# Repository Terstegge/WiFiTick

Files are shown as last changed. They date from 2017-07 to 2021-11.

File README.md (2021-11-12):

# WiFiTick
Small ESP8266-based WLAN board for the MSP432 launchpad.

Here you see WiFiTick attached to the MSP432 launchpad with an
additional EDU MKII booster pack above:

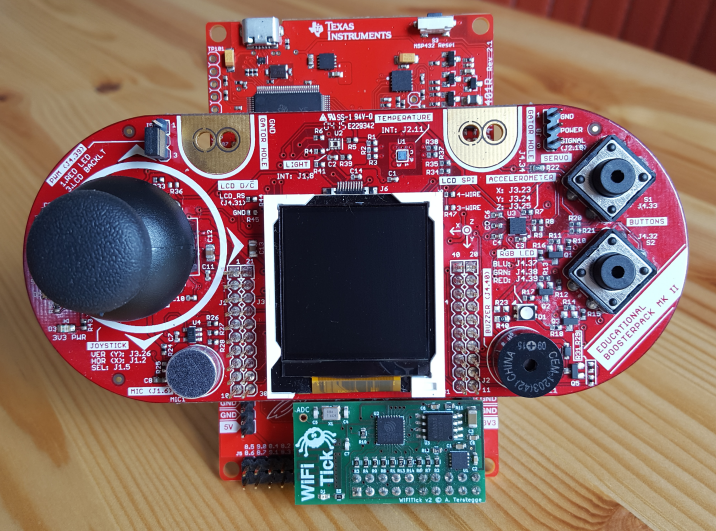
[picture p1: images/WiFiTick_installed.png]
WiFiTick picture 1


WiFiTick front and back view:

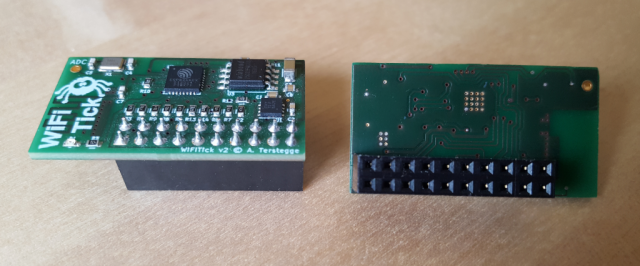
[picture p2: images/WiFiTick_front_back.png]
WiFiTick picture 2


WiFiTick is a small add-on board for the
[MSP432 lauchpad](http://www.ti.com/tool/MSP-EXP432P401R) from Texas Instruments.
The MSP432 launchpad is a nice microcontroller board with a Cortex M4F processor
and a on-board debug facility. WiFiTick adds WiFi functionality to the lauchpad,
using a ESP8266, which is a cheap but very powerful WLAN-enabled microcontroller
from Espressif.

Texas Instruments have their own WiFi solution (e.g. the CC3100 booster pack).
But these boards have to be disconnected from the lauchpad when you want to 
flash a new firmware to the WiFi board. This makes it a little bit unhandy for
students.

WiFiTick has the following features:

* Low cost - ideal for WiFi enabled student projects
  (WiFi client and WiFi access point modes available)
* 4 MiB flash, so lots of space for ESP8266 programs and
  embedded file systems (SPIFFS) 
* Integrated PCB antenna
* Single 5V power supply (via USB/launchpad). There is a separate
  3.3V regulator on the board.
* No interference with other booster packs, because the additional 
  horizontal header of the MSP432 lauchpad is used
* No need to disconnect from launchpad: With a special software, the MSP432
  launchpad serves as a programming adapter (via a UART interface). This
  software features automatic baud rate control, so boot messages of the
  ESP8266 are readable.
* Easy programming of ESP8266 with Arduino IDE
* Full control of the ESP8266 from MSP432 side. The MSP432 can ...
    * Reset, Power up/down or wake up the ESP8266
    * Communicate with the ESP8266 via SPI (or any other protocol -
      there are 8 GPIOs plus the programming UART available for
      data exchange).
* Additional ADC input pad for the ESP8266
* User-controllable LED on the board (can e.g. simulate the behaviour of the
  LED on the well-known ESP-12E/F boards)

This project contains the hardware design files, which were developed
using [KiCad EDA](http://kicad.org/). The related software will be
published in a separate project.

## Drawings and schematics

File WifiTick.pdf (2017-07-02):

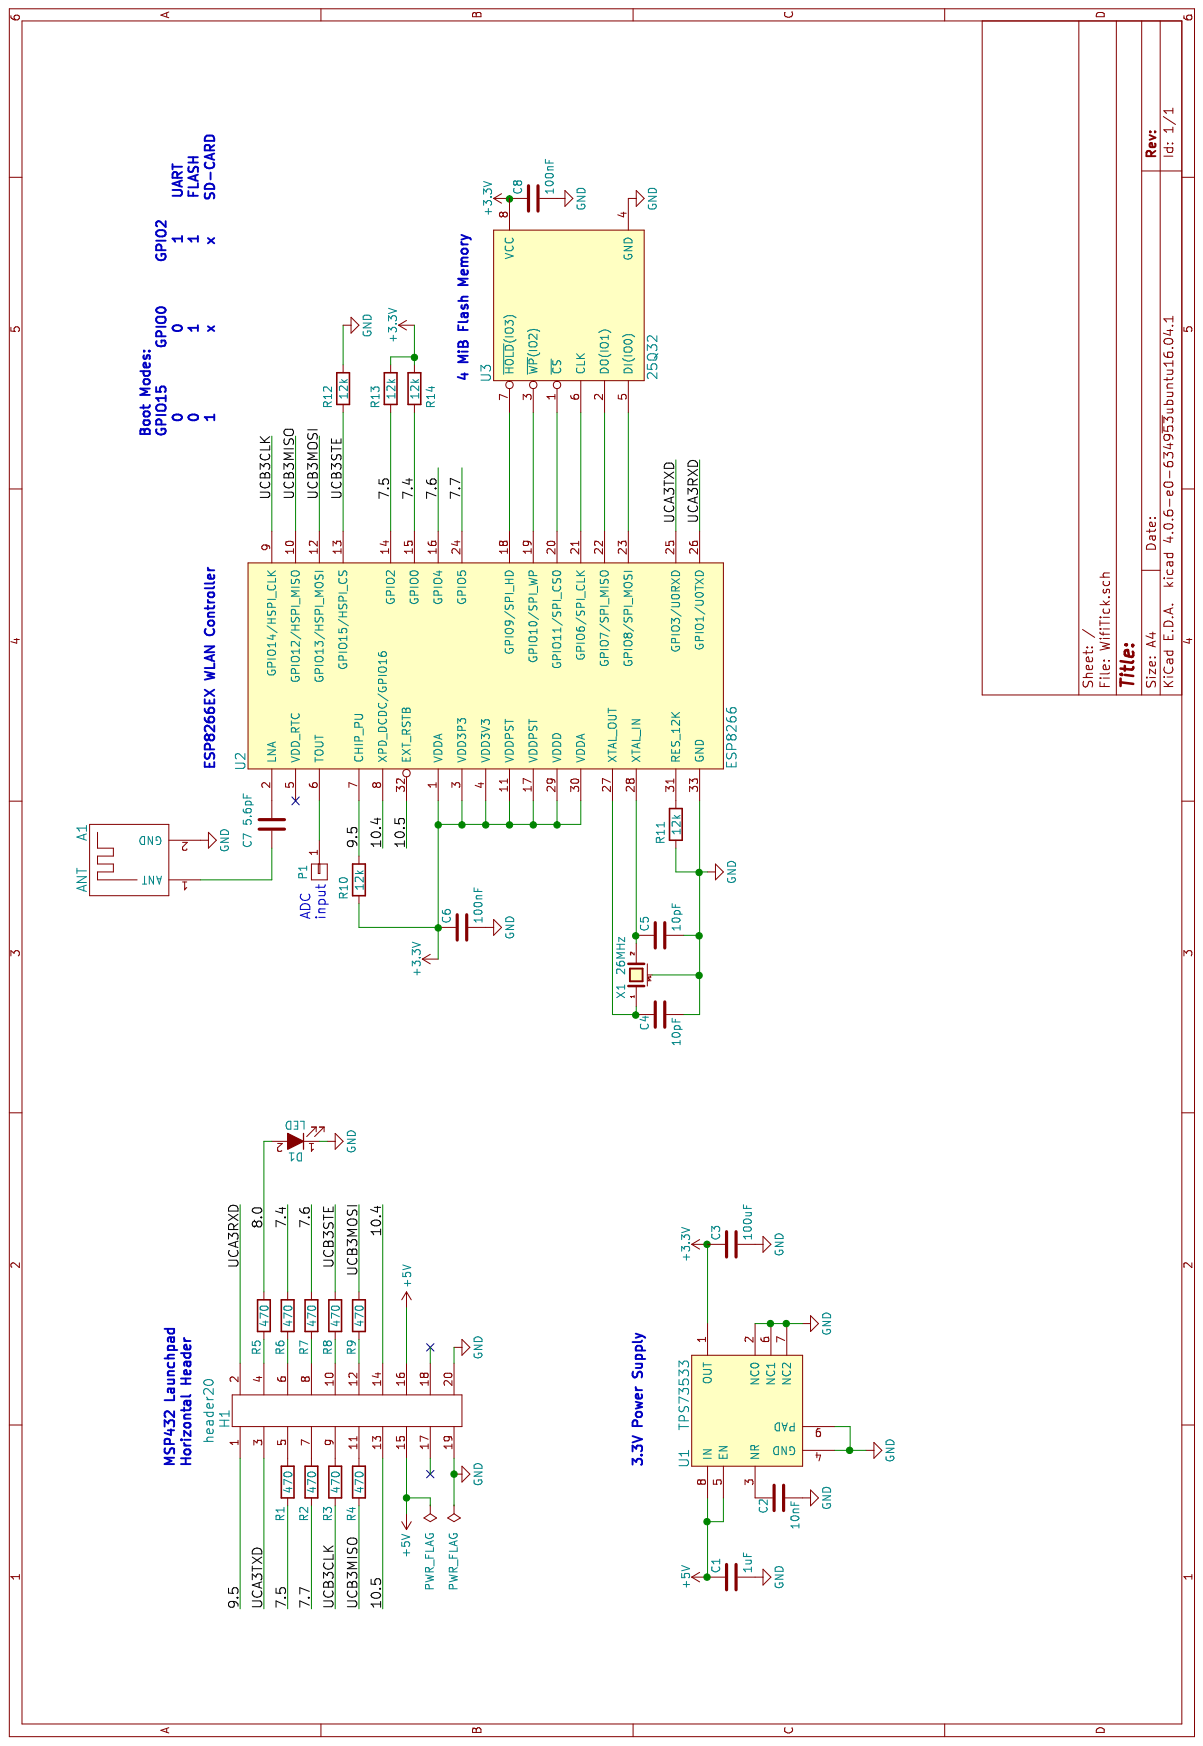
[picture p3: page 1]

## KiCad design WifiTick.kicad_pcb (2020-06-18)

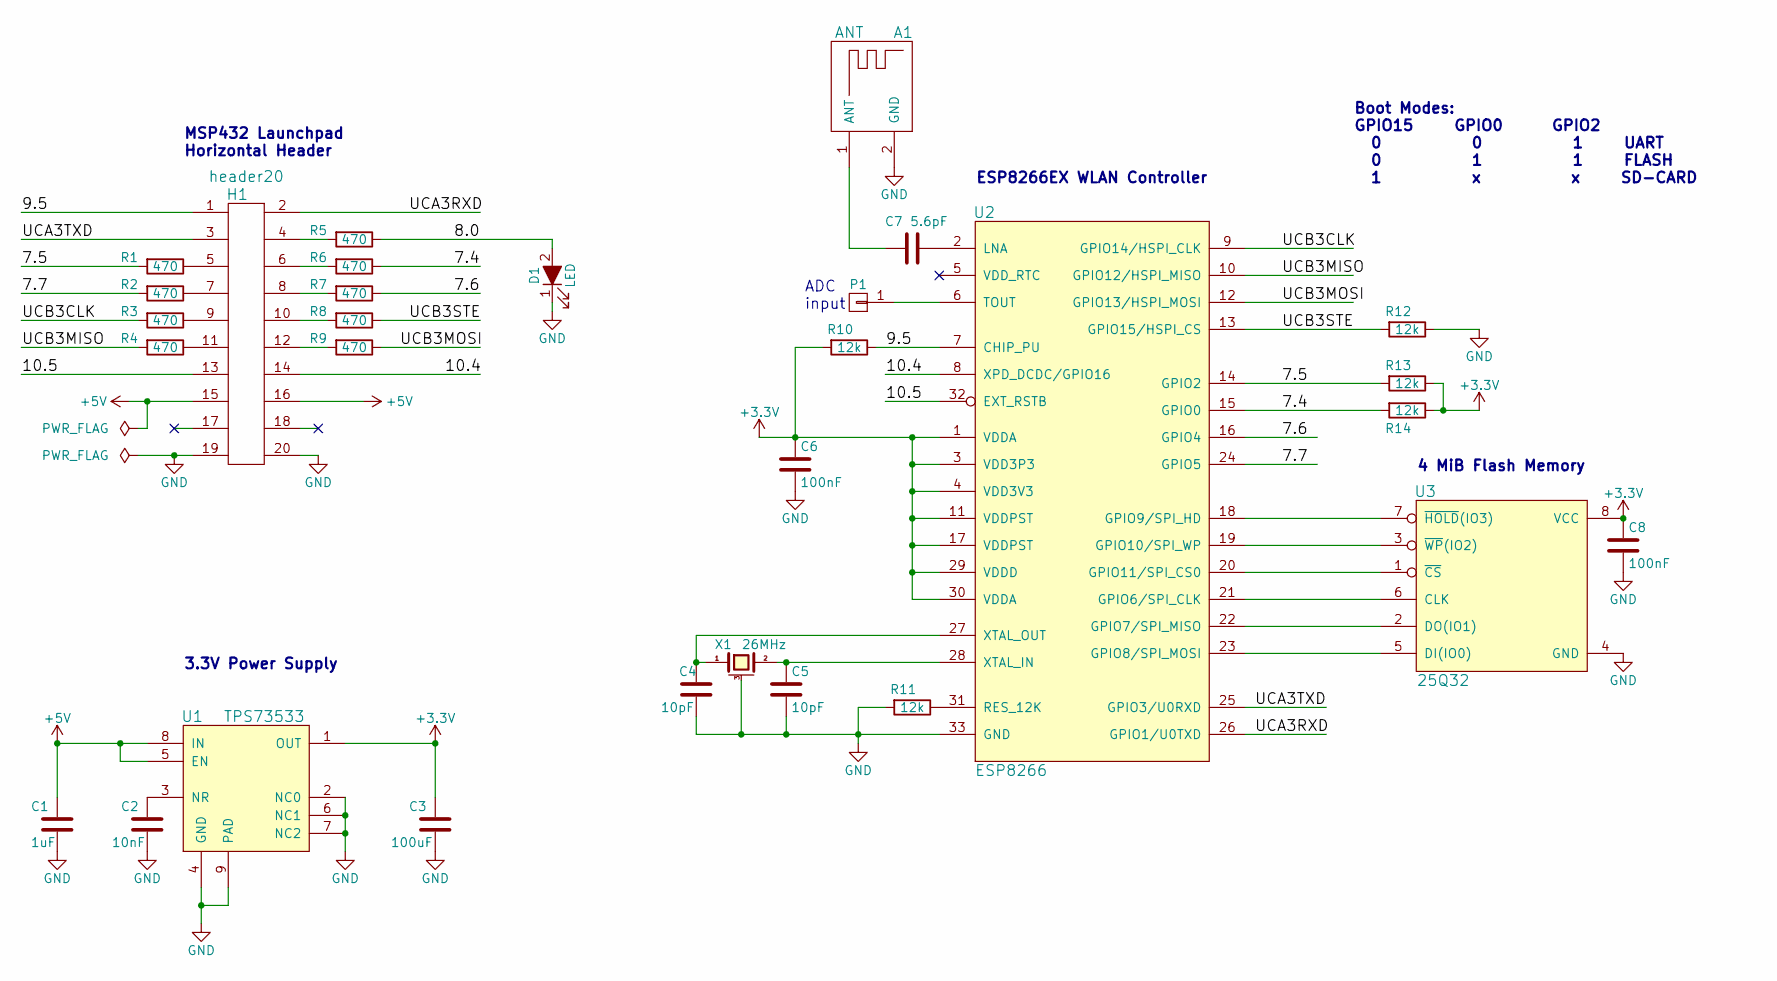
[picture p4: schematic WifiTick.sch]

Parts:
A1: ANT; WIFI_ANTENNA_MIRROR
C1: 1uF; C_0603
C2: 10nF; C_0603
C3: 100uF; C_1206
C4, C5: 10pF; C_0603
C6, C8: 100nF; C_0603
C7: 5.6pF; C_0603
D1: LED; LED_0603
H1: header20; Socket_Strip_Straight_2x10
P1: CONN_01X01; 1x1_Solderpad
R1, R2, R3, R4, R5, R6, R7, R8, R9: 470; R_0603
R10, R11, R12, R13, R14: 12k; R_0603
U1: TPS73533; VSON-8
U2: ESP8266; QFN-32-1EP_5x5mm_Pitch0.5mm
U3: 25Q32; SOIJ-8_5.3x5.3mm_Pitch1.27mm
X1: 26MHz; crystal_FA238-TSX3225

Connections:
+3V3: C3.1, C6.1, C8.1, R10.2, R13.1, R14.1, U1.1 (OUT), U2.1 (VDDA), U2.3 (VDD3P3), U2.4 (VDD3V3), U2.11 (VDDPST), U2.17 (VDDPST), U2.29 (VDDD), U2.30 (VDDA), U3.8 (VCC)
+5V: C1.1, H1.15, H1.16, U1.5 (EN), U1.8 (IN)
/7.4: R6.1, R14.2, U2.15 (GPIO0)
/7.5: R1.2, R13.2, U2.14 (GPIO2)
/7.6: R7.1, U2.16 (GPIO4)
/7.7: R2.2, U2.24 (GPIO5)
/8.0: D1.2 (A), R5.1
/9.5: H1.1, R10.1, U2.7 (CHIP_PU)
/10.4: H1.14, U2.8 (XPD_DCDC/GPIO16)
/10.5: H1.13, U2.32 (EXT_RSTB)
/UCA3RXD: H1.2, U2.26 (GPIO1/U0TXD)
/UCA3TXD: H1.3, U2.25 (GPIO3/U0RXD)
/UCB3CLK: R3.2, U2.9 (GPIO14/HSPI_CLK)
/UCB3MISO: R4.2, U2.10 (GPIO12/HSPI_MISO)
/UCB3MOSI: R9.1, U2.12 (GPIO13/HSPI_MOSI)
/UCB3STE: R8.1, R12.2, U2.13 (GPIO15/HSPI_CS)
GND: A1.2 (GND), C1.2, C2.2, C3.2, C4.2, C5.2, C6.2, C8.2, D1.1 (K), H1.19, H1.20, R11.2, R12.1, U1.2 (NC0), U1.4 (GND), U1.6 (NC1), U1.7 (NC2), U1.9 (PAD), U2.33 (GND), U3.4 (GND), X1.3 (case); also elsewhere on the board
unnamed: A1.1 (ANT), C7.1
unnamed: C2.1, U1.3 (NR)
unnamed: C4.1, U2.27 (XTAL_OUT), X1.1
unnamed: C5.1, U2.28 (XTAL_IN), X1.2
unnamed: C7.2, U2.2 (LNA)
unnamed: H1.4, R5.2
unnamed: H1.5, R1.1
unnamed: H1.6, R6.2
unnamed: H1.7, R2.1
unnamed: H1.8, R7.2
unnamed: H1.9, R3.1
unnamed: H1.10, R8.2
unnamed: H1.11, R4.1
unnamed: H1.12, R9.2
unnamed: P1.1, U2.6 (TOUT)
unnamed: R11.1, U2.31 (RES_12K)
unnamed: U2.18 (GPIO9/SPI_HD), U3.7 (~HOLD~(IO3))
unnamed: U2.19 (GPIO10/SPI_WP), U3.3 (~WP~(IO2))
unnamed: U2.20 (GPIO11/SPI_CS0), U3.1 (~CS)
unnamed: U2.21 (GPIO6/SPI_CLK), U3.6 (CLK)
unnamed: U2.22 (GPIO7/SPI_MISO), U3.2 (DO(IO1))
unnamed: U2.23 (GPIO8/SPI_MOSI), U3.5 (DI(IO0))

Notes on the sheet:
3.3V Power Supply
MSP432 Launchpad Horizontal Header
4 MiB Flash Memory
ESP8266EX WLAN Controller
ADC input
Boot Modes: GPIO15 GPIO0 GPIO2 0 0 1 UART 0 1 1 FLASH 1 x x SD-CARD

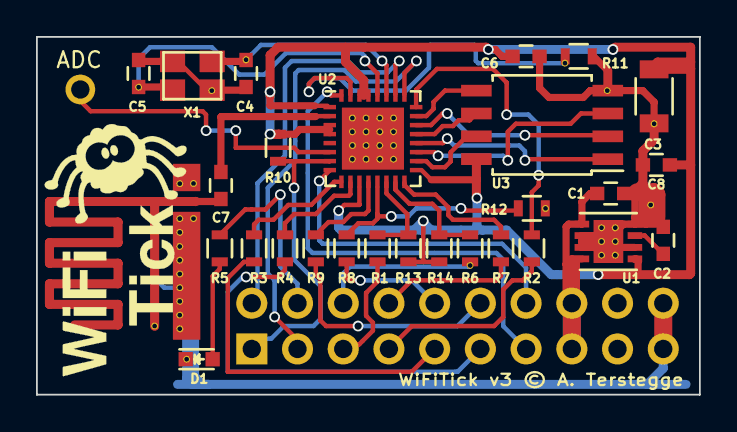
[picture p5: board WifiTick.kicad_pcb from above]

Board: 2 copper layers, 36.8 x 19.9 mm, 31 parts (1 on the bottom side), 39 nets.

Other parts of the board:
GND: Stiching Via; StichingVia

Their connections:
GND: GND.1; also elsewhere on the board

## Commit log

2017-07-02 First version of public files. KiCad libs might be a little bit messy...
    [WifiTick.kicad_pcb, WifiTick.sch]
2017-07-02 Some library cleanup. Generated Gerber files.
    [WifiTick-B.Cu.gbr, WifiTick-B.Mask.gbr, WifiTick-B.Paste.gbr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]
2020-06-18 Update due to new KiCad version.
    [WifiTick-2020-06-18-15-53-54.sch, WifiTick.kicad_pcb, WifiTick.sch]
2021-11-12 Updated link to KiCad.

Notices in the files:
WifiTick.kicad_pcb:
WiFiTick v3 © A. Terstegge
